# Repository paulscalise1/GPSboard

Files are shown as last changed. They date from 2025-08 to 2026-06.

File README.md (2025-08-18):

# GPS Board v3.0 r1.1

This board is designed for ECEN-435 at the University of Nebraska-Lincoln (Scott Campus).
GPS coordinates will print via CAN every 4 seconds. All GPS information sent over CAN is ASCII encoded.
To obtain a lock, you must have a direct line of sight to the sky!!
For CAN transmissions to work properly, the CAN resistor header (CAN R) must be shorted, allowing for proper termination.

Example Messages:

Message with no GPS Lock: ```LA00.00NLO000.0E```

Message with GPS Lock: ```LA41.14NLO096.0W```

## CAN Parameters

CAN is enabled by default at 100 kbps with the following parameters.

Bit Timing Parameters:
System Clock --> ```HSI48```
Prescaler (for Time Quantum) --> ```120```
Time Quanta in Bit Segment 1 --> ```2 Times```
Time Quanta in Bit Segment 2 --> ```1 Time```
ReSynchronization Jump Width --> ```1 Time```

All Basic Parameters --> ```Disabled```

Advanced Parameters:
Operating Mode --> ```Normal```

## Firmware

The entire CubeIDE project for the STM32F042F4P6 is found in the Firmware folder.

## Connections

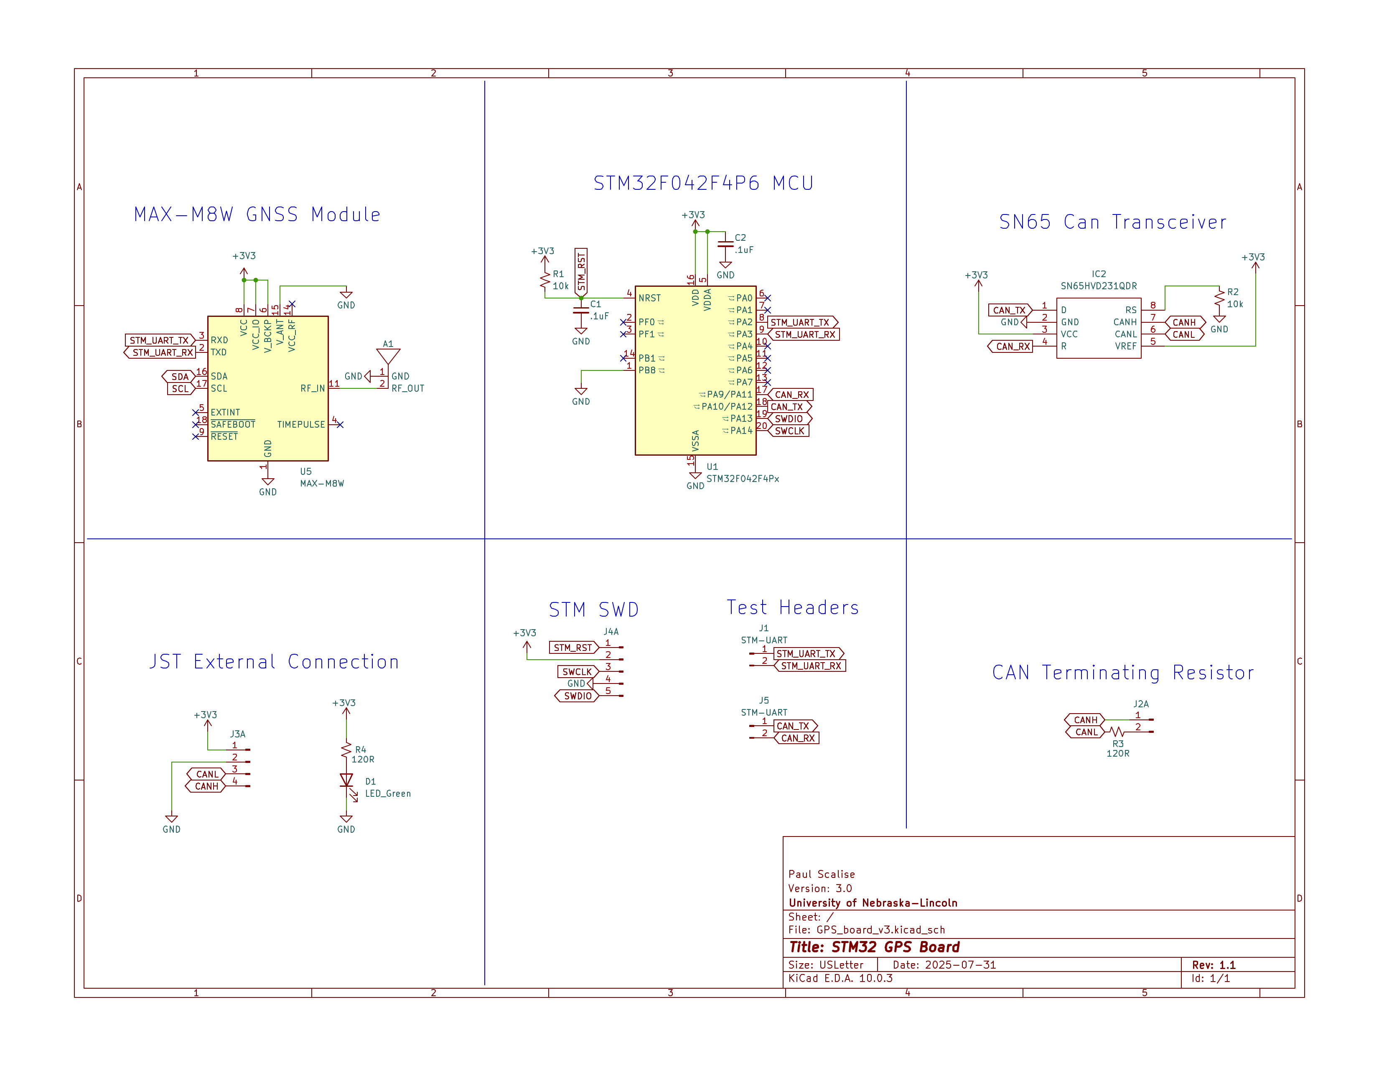
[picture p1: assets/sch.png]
schematic


## Board

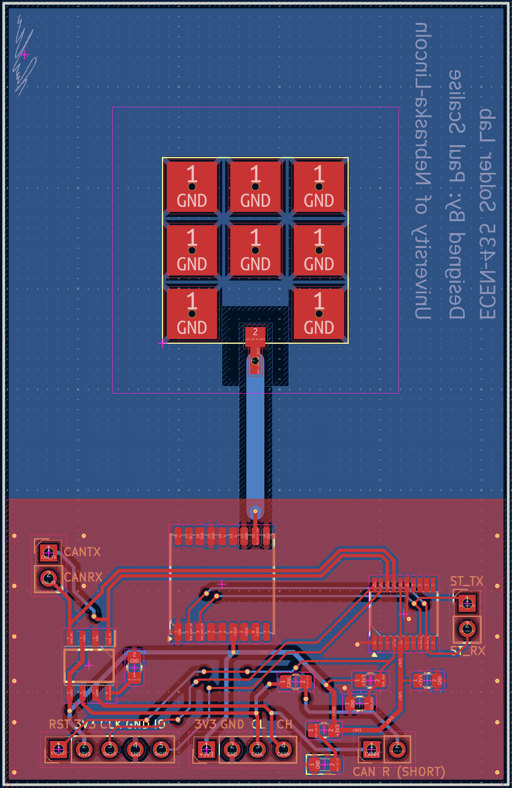
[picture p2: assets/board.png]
board


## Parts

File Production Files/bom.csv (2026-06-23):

Designator | Footprint | Quantity | Value | Man. Part # | Price $ (at 10 quantity) | Mouser Link
A1 | L000953-01 | 1 | ~ | L000953-01 | 3.16 | https://www.mouser.com/ProductDetail/TE-Connectivity-Linx-Technologies/L000953-01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
C1, C2 | 805 | 2 | .1uF | 0805ZD104KAT2A | 0.04 | https://www.mouser.com/ProductDetail/KYOCERA-AVX/0805ZD104KAT2A?qs=qVfB0%2FDaMDZM7gCosjcOHQ%3D%3D
D1 | 805 | 1 | LED_Green | LTST-S220GKT | 0.095 | https://www.mouser.com/ProductDetail/LITEON/LTST-S220GKT?qs=NUb82WqeCyoiEaTE8OXgMg%3D%3D
IC2 | SOIC127P600X175-8N | 1 | SN65HVD231QDR | SN65HVD231QDR | 2.63 | https://www.mouser.com/ProductDetail/Texas-Instruments/SN65HVD231QDR?qs=QViXGNcIEAvbXcoRvmoe%2Fw%3D%3D
J1, J2 | PinHeader_1x02_P2.54mm_Vertical | 2 | ~
J3 | PinHeader_1x04_P2.54mm_Vertical | 1 | ~
J4 | PinHeader_1x05_P2.54mm_Vertical | 1 | ~ | M20-9992046 | 0.589 | https://www.mouser.com/ProductDetail/Harwin/M20-9992046?qs=%252Bk6%2F5FB6qrkVgm0dNoxueg%3D%3D
R1, R2 | 805 | 2 | 10k | RT0805DRE0710KL | 0.023 | https://www.mouser.com/ProductDetail/YAGEO/RT0805DRE0710KL?qs=%2Ff7pOCXLR5e34KOT0xwLAQ%3D%3D
R3, R4 | 805 | 2 | 120R | RT0805FRE13120RL | 0.035 | https://www.mouser.com/ProductDetail/YAGEO/RT0805FRE13120RL?qs=1mbolxNpo8ewZR92p1jJeQ%3D%3D
U1 | TSSOP-20_4.4x6.5mm_P0.65mm | 1 | STM32F042F4Px | STM32F042F4P6 | 2.14 | https://www.mouser.com/ProductDetail/STMicroelectronics/STM32F042F4P6?qs=4b8myOmUP%252BvvhAaQx2eFdg%3D%3D
U5 | ublox_MAX_gps | 1 | MAX-M8C | MAX-M8C-0 | 16.2 | https://www.mouser.com/ProductDetail/u-blox/MAX-M8C-0?qs=DPoM0jnrROVJTO3yBNKlcw%3D%3D
 |  |  |  | Price per student $ (at 10 board quantity): | 24.58805

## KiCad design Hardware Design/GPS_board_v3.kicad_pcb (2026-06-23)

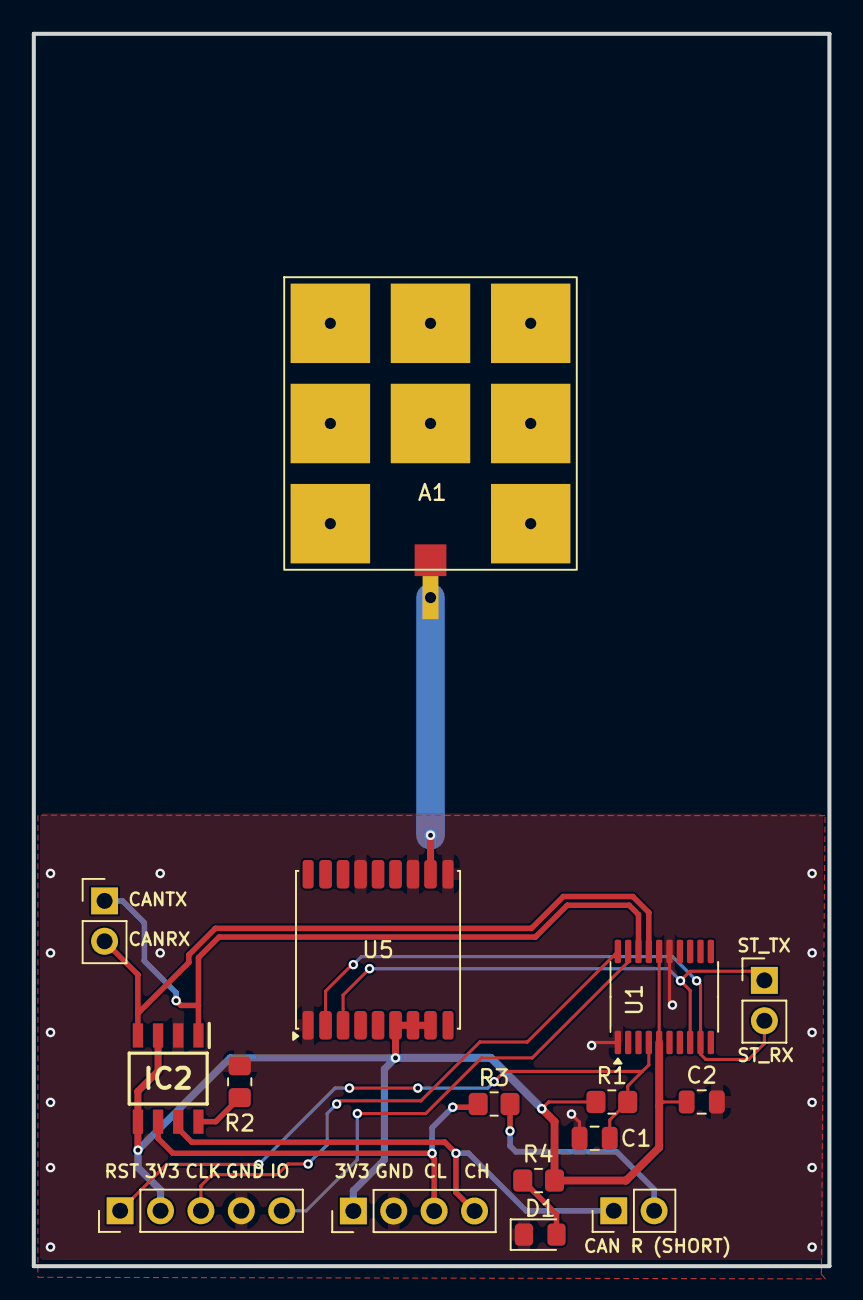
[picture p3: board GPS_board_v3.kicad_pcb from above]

Board: 2 copper layers, 50.0 x 77.5 mm, 16 parts (0 on the bottom side), 15 nets.

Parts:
A1: L000953-01
C1, C2: .1uF; C_0805_2012Metric
D1: LED_Green; LED_0805_2012Metric_Pad1.15x1.40mm_HandSolder
IC2: SN65HVD231QDR; SOIC127P600X175-8N
J1, J5: STM-UART; PinHeader_1x02_P2.54mm_Vertical
J2: PinHeader_1x02_P2.54mm_Vertical
J3: PinHeader_1x04_P2.54mm_Vertical
J4: PinHeader_1x05_P2.54mm_Vertical
R1, R2: 10k; R_0805_2012Metric_Pad1.20x1.40mm_HandSolder
R3, R4: 120R; R_0805_2012Metric_Pad1.20x1.40mm_HandSolder
U1: STM32F042F4Px; TSSOP-20_4.4x6.5mm_P0.65mm
U5: MAX-M8W; ublox_MAX

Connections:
+3V3: C2.1, IC2.3 (VCC), IC2.5 (VREF), J3.1, J4.2, R1.1, R4.2, U1.5 (VDDA), U1.16 (VDD), U5.6 (V_BCKP), U5.7 (VCC_IO), U5.8 (VCC)
CANH: IC2.7 (CANH), J2.1, J3.4
CANL: IC2.6 (CANL), J3.3, R3.1
CAN_RX: IC2.4 (R), J5.2, U1.17 (PA9/PA11)
CAN_TX: IC2.1 (D), J5.1, U1.18 (PA10/PA12)
GND: A1.1 (GND), C1.2, C2.2, D1.1 (K), IC2.2 (GND), J3.2, J4.4, R2.2, U1.1 (PB8), U1.15 (VSSA), U5.1 (GND), U5.10 (GND), U5.12 (GND), U5.15 (V_ANT)
unnamed: A1.2 (RF_OUT), U5.11 (RF_IN)
unnamed: D1.2 (A), R4.1
unnamed: IC2.8 (RS), R2.1
unnamed: J2.2, R3.2
STM_RST: C1.1, J4.1, R1.2, U1.4 (NRST)
STM_UART_RX: J1.2, U1.9 (PA3), U5.2 (TXD)
STM_UART_TX: J1.1, U1.8 (PA2), U5.3 (RXD)
SWCLK: J4.3, U1.20 (PA14)
SWDIO: J4.5, U1.19 (PA13)

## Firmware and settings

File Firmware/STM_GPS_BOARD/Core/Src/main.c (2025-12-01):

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
/* Includes ------------------------------------------------------------------*/
#include "main.h"

/* USER CODE BEGIN Includes */
#include <string.h>
#include <stdbool.h>
/* USER CODE END Includes */

CAN_HandleTypeDef hcan;

TIM_HandleTypeDef htim14;

UART_HandleTypeDef huart2;

/* USER CODE BEGIN PV */
uint8_t uart_rx_buf[128] = {0};
volatile bool measure_flag = false;
uint8_t frameBuffer[100];
uint8_t lat[8];
uint8_t lon[8];
uint8_t fixedlat[8] = {"LA00.00N"};
uint8_t fixedlon[8] = {"LO000.0E"};

uint8_t gpsOn[8]       = {0xB5,0x62,0x06,0x57,0x00,0x00,0x5D,0x1D};
uint8_t pwrControl[16] = {0xB5,0x62,0x06,0x86,0x08,0x00,0x00,0x03,0x00,0x00,0x00,0x00,0x00,0x00,0x97,0x6F};
uint8_t pwrControl2[8] = {0xB5,0x62,0x06,0x86,0x00,0x00,0x8C,0xAA};
uint8_t coldRestart[12]= {0xB5,0x62,0x06,0x04,0x04,0x00,0xFF,0xFF,0x02,0x00,0x0E,0x61};
/* USER CODE END PV */

void SystemClock_Config(void);
static void MX_GPIO_Init(void);
static void MX_CAN_Init(void);
static void MX_USART2_UART_Init(void);
static void MX_TIM14_Init(void);
/* USER CODE BEGIN PFP */
static void gpsCommand(const uint8_t *d, uint8_t len);
static uint8_t uartRecv(void);
static void uartWrite(uint8_t b);
static uint8_t getFrame(void);
static void processFrame(uint8_t size);
static void CAN_Send8(const uint8_t *payload8, uint16_t std_id);
/* USER CODE END PFP */

/* USER CODE BEGIN 0 */
void HAL_TIM_PeriodElapsedCallback(TIM_HandleTypeDef *htim)
{
  if (htim->Instance == TIM14) {
    measure_flag = true;
  }
}
/* USER CODE END 0 */

/**
  * @brief  The application entry point.
  * @retval int
  */
int main(void)
{

  /* MCU Configuration--------------------------------------------------------*/

  /* Reset of all peripherals, Initializes the Flash interface and the Systick. */
  HAL_Init();

  /* Configure the system clock */
  SystemClock_Config();

  /* Initialize all configured peripherals */
  MX_GPIO_Init();
  MX_CAN_Init();
  MX_USART2_UART_Init();
  MX_TIM14_Init();
  /* USER CODE BEGIN 2 */

  HAL_CAN_Start(&hcan);

  // Configure an accept-all CAN filter into FIFO0
  CAN_FilterTypeDef f = {0};
  f.FilterBank = 0;
  f.FilterMode = CAN_FILTERMODE_IDMASK;
  f.FilterScale = CAN_FILTERSCALE_32BIT;
  f.FilterIdHigh = 0x0000;
  f.FilterIdLow  = 0x0000;
  f.FilterMaskIdHigh = 0x0000;
  f.FilterMaskIdLow  = 0x0000;
  f.FilterFIFOAssignment = CAN_FILTER_FIFO0;
  f.FilterActivation = ENABLE;
  HAL_CAN_ConfigFilter(&hcan, &f);

  // 4s interrupt to get new coordinates
  HAL_TIM_Base_Start_IT(&htim14);

  // Initialize GPS (MAX-M8C-0)
  gpsCommand(gpsOn,       sizeof(gpsOn));
  gpsCommand(pwrControl,  sizeof(pwrControl));
  gpsCommand(pwrControl2, sizeof(pwrControl2));
  gpsCommand(coldRestart, sizeof(coldRestart));
  /* USER CODE END 2 */

  /* Infinite loop */
  /* USER CODE BEGIN WHILE */
  while (1) {
    if (measure_flag) {
      measure_flag = false;

      uint8_t n = getFrame();
      if (n > 0) {
        processFrame(n);
        // Send two 8-byte frames with the lat/lon strings
        CAN_Send8(lat, 0x101);
        CAN_Send8(lon, 0x101);
      }
    }
    /* USER CODE END WHILE */

    /* USER CODE BEGIN 3 */
  }
  /* USER CODE END 3 */
}

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
/* USER CODE BEGIN 4 */
static void gpsCommand(const uint8_t *d, uint8_t len)
{
  HAL_UART_Transmit(&huart2, (uint8_t*)d, len, HAL_MAX_DELAY);
}

static void uartWrite(uint8_t b)
{
  HAL_UART_Transmit(&huart2, &b, 1, HAL_MAX_DELAY);
}

__inline static uint8_t uartRecv(void)
{
  uint8_t b;
  HAL_UART_Receive(&huart2, &b, 1, 100);
  return b;
}

static uint8_t getFrame(void)
{
  uint8_t frameSize = 0;
  bool receive = true, gotHeader = false;
  uint8_t hdr[5];

  while (receive) {
    while (!gotHeader) {
      uint8_t c = uartRecv();
      if (c == '$') {
        for (int i = 0; i < 5; i++){
        	hdr[i] = uartRecv();
        }
        gotHeader = (hdr[0]=='G' && hdr[1]=='N' && hdr[2]=='G' && hdr[3]=='L' && hdr[4]=='L');
      }
    }
    uint8_t c = uartRecv();
    if (c == '$') {
      receive = false;
    } else {
      if (frameSize < sizeof(frameBuffer)) frameBuffer[frameSize++] = c;
    }
  }
  return frameSize;
}

static void processFrame(uint8_t size)
{
  uint8_t commas[7] = {0};
  int i = 0, j = 0;

  while (i < 7 && j < size) {
      if (frameBuffer[j] == ',') {
          commas[i++] = j;
      }
      j++;
  }

  if (i < 6 || frameBuffer[commas[5] + 1] == 'V' || (commas[1] - commas[0] < 2)) {
    memcpy(lat, fixedlat, sizeof(lat));
    memcpy(lon, fixedlon, sizeof(lon));
    return;
  }

  // LAT: "LA00.00N" from ddmm.mmmm,N/S
  lat[0]='L'; lat[1]='A';
  lat[2] = frameBuffer[commas[0] + 1];
  lat[3] = frameBuffer[commas[0] + 2];
  lat[4] = '.';
  lat[5] = frameBuffer[commas[0] + 3];
  lat[6] = frameBuffer[commas[0] + 4];
  lat[7] = frameBuffer[commas[1] + 1];

  // LON: "LO000.0E" from dddmm.mmmm,E/W
  lon[0]='L'; lon[1]='O';
  lon[2] = frameBuffer[commas[2] + 1];
  lon[3] = frameBuffer[commas[2] + 2];
  lon[4] = frameBuffer[commas[2] + 3];
  lon[5] = '.';
  lon[6] = frameBuffer[commas[2] + 4];
  lon[7] = frameBuffer[commas[3] + 1];
}

static void CAN_Send8(const uint8_t *payload8, uint16_t std_id)
{
  CAN_TxHeaderTypeDef hdr;
  hdr.StdId = std_id;
  hdr.ExtId = 0;
  hdr.IDE   = CAN_ID_STD;
  hdr.RTR   = CAN_RTR_DATA;
  hdr.DLC   = 8;
  hdr.TransmitGlobalTime = DISABLE;

  uint32_t mb;
  HAL_CAN_AddTxMessage(&hcan, &hdr, (uint8_t*)payload8, &mb);
}
/* USER CODE END 4 */
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


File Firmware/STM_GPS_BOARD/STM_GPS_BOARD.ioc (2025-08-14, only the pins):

Mcu.UserName=STM32F042F4Px
PA11.Signal=CAN_RX
PA12.Signal=CAN_TX
PA13.Signal=SYS_SWDIO
PA14.Signal=SYS_SWCLK
PA2.Signal=USART2_TX
PA3.Signal=USART2_RX

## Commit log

2025-08-14 added STM32 firmware files
2025-08-18 final updated board + prod files
    [GPS_board_v3-B_Cu.gbr, GPS_board_v3-B_Mask.gbr, GPS_board_v3-B_Paste.gbr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]
2025-12-01 added antenna ground pads to F_Paste for stencil
    [GPS_board_v3-B_Cu.gbr, GPS_board_v3-B_Mask.gbr, GPS_board_v3-B_Paste.gbr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]
2026-06-23 Added testing headers.
    [GPS_board_v3-B_Cu.gbr, GPS_board_v3-B_Mask.gbr, GPS_board_v3-B_Paste.gbr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]

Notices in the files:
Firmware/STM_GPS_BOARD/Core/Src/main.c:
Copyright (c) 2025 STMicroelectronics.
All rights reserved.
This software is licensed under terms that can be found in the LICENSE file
